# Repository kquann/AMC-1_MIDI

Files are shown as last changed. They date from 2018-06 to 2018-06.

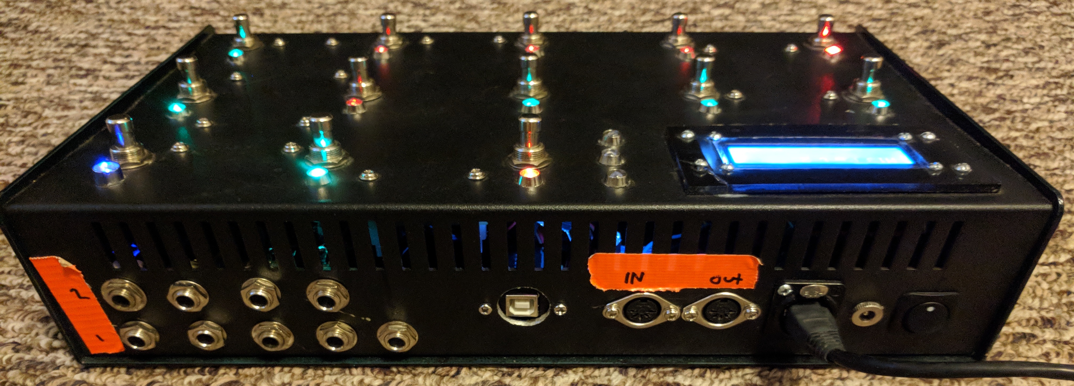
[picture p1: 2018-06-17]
resources/Photos/Back.jpg

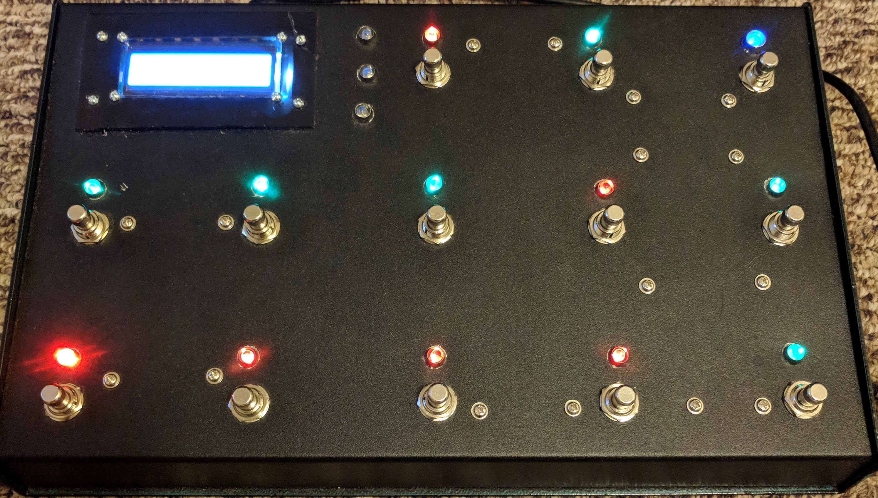
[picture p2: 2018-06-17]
resources/Photos/Front.jpg

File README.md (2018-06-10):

# AMC-1
Arduino-based MIDI foot controller

General:  
-This is a general purpose MIDI foot controller based around an Arduino Uno microcontroller.  
-Please see associated parts list and schematic for details.  
-Makes use of ShiftPWM (from elcojacobs), MIDI (from Forty Seven Effects) and LiquidCrystal595 (from tehniq3) libraries. Make sure these are placed appropriately in your Ardunio IDE library directory.  
-The controller itself has 13 switches (10 multi-use, 1 page up, 1 page down and 1 tap-tempo).  
-Support for 3 additional external switches also supported.  
-Each of 13-switches + Ext switching jacks has a multi-colored RGB LED.  
-Supports 6 expression pedals (TRS-style).  
-Interface is set up in "Pages", whereby you can scroll through different pages of presets/IAs, etc.
Each page consists of 10 different buttons, scrolling the page number increments/decrements through pages.
For instance page 1 = effects 1-10, page 2 = 11-20, etc. Note indexing starts at 0.  
-Current set-up is here as an example, change as you see fit!  

Issues:  
-Controller settings currently only changeable by modifying this code and re-flashing.  
-Make sure to disconnect MIDI out from any devices while flashing over USB!  
-MIDI over USB not tested.  
-Currently no expression calibration function.  
-MIDI in not extensively tested.  
-External switches not implemented in code.  
-While unit can support up to 6 expression pedals, code is currently set up for 1.  
-Code can be optimized (it's old), particularly with presets, but it gets the job done.

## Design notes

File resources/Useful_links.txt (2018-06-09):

Useful links:
http://www.instructables.com/id/Hookup-a-16-pin-HD44780-LCD-to-an-Arduino-in-6-sec/?ALLSTEPS
http://playground.arduino.cc/Code/ShiftRegSN74HC165N
http://www.instructables.com/id/MIDI-TO-ARDUINO/?ALLSTEPS 
https://github.com/FortySevenEffects/arduino_midi_library/
http://www.notesandvolts.com/2012/01/fun-with-arduino-midi-input-basics.html
http://www.indiana.edu/~emusic/etext/MIDI/chapter3_MIDI4.shtml
http://playground.arduino.cc/Main/MIDILibraryReference 
http://www.elcojacobs.com/using-shiftpwm-to-control-rgb-leds-with-arduino/
http://forum.arduino.cc/index.php?topic=122378.0
http://www.instructables.com/id/Home-Made-Bezel-Window-for-LCD-LED-Displays/?ALLSTEPS

Similar projects:
http://dikant.de/2015/01/18/diy-midi-footswitch-controller/
http://www.codeproject.com/Articles/38203/Arduino-Based-MIDI-Expression-Pedal
http://www.midikits.net/foot_pedal_USB_assem/foot_switch_pedal_USB_assem.htm
http://www.maxgreco.com/fun/microfoot/

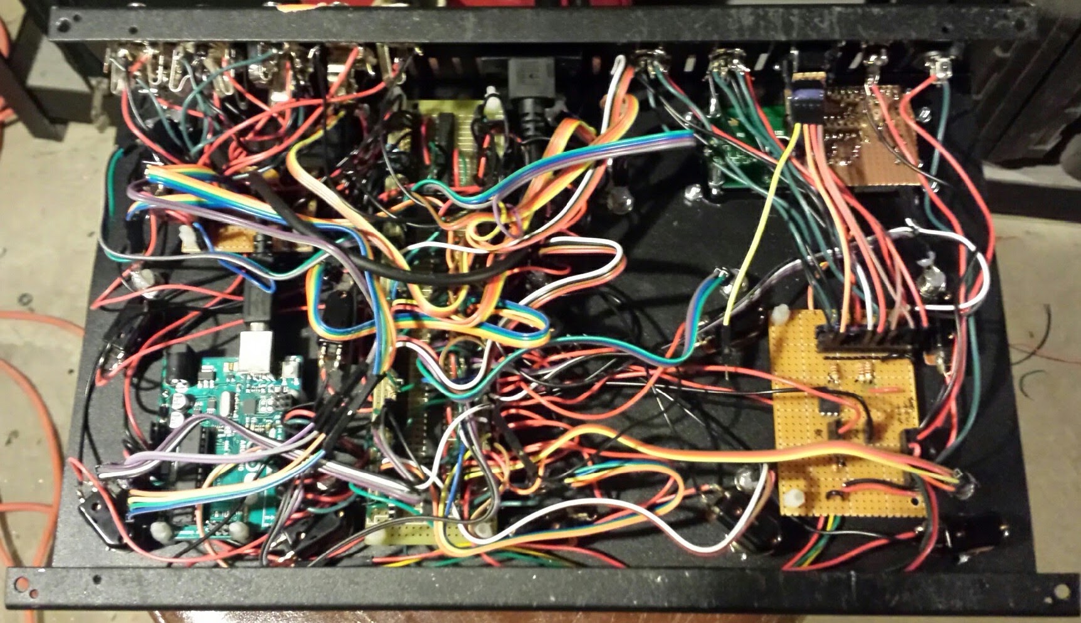
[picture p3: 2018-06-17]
resources/Photos/Inside.jpg

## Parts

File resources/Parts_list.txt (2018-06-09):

Part Name	Vendor	Cat #	Quantity	Unit Cost	Ext Cost	Link	Notes
Common Anode RGB LED (5mm)	Tayda	N/A	16	0.27	4.32	http://www.taydaelectronics.com/rgb-led-5mm.html	
Soft-touch SPST Switch	Tayda	N/A	13	1.99	25.87	http://www.taydaelectronics.com/spst-momentary-soft-touch-push-button-stomp-foots-pedal-switch.html	
"6.35MM 1/4"" STEREO CHASSIS SOCKET / JACK 3 TERMINALS"	Tayda	N/A	6	1.16	6.96	http://www.taydaelectronics.com/hardware/6-35mm-1-4-plugs-jacks/6-35mm-1-4-stereo-chassis-socket-jack-3-terminals.html	
74HC595 8 BIT SHIFT REGISTER IC	Tayda	N/A	1	0.29	0.29	http://www.taydaelectronics.com/74hc595-8-bit-shift-register-ic.html	
74HC165 74165 IC 8 BIT SHIFT REGISTER (PISO for output)	Tayda	N/A	2	0.34	0.68	http://www.taydaelectronics.com/74hc165-74165-ic-8-bit-shift-register.html	
LCD DISPLAY 16 X 2 BLUE CHARACTER WITH BACKLIGHT	Tayda	N/A	1	5.9	5.9	http://www.taydaelectronics.com/lcd-displays/lcd-display-16-x-2-blue-character-with-backlight.html	
5MM BEZEL LED HOLDER CHROME METAL	Tayda	N/A	16	0.17	2.72	http://www.taydaelectronics.com/leds/led-holders-bezels/5mm-bezel-led-holder-chrome-metal.html	
Hammond 1456PH1BKBU Enclosure	Mouser	546-1456PH1BKBU	1	34.09	34.09	http://www.mouser.com/ProductDetail/Hammond-Manufacturing/1456PH1BKBU/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	
BC550 NPN BJT	Mouser	821-BC550C-A1	1	0.13	0.13	http://www.mouser.com/Search/ProductDetail.aspx?R=BC550C_A1virtualkey53310000virtualkey821-BC550C-A1	
1K Resistor	Mouser	291-1K-RC	6	0.1	0.6	http://www.mouser.com/Search/ProductDetail.aspx?R=291-1K-RCvirtualkey21980000virtualkey291-1K-RC	
TLC5916 Shift Register	Mouser	595-TLC5916IN	6	1.54	9.24	http://www.mouser.com/Search/ProductDetail.aspx?R=TLC5916INvirtualkey59500000virtualkey595-TLC5916IN	
4N25 Optocoupler	Mouser	859-4N25	1	0.42	0.42	http://www.mouser.com/Search/ProductDetail.aspx?R=4N25virtualkey57820000virtualkey859-4N25	
3.3K resistor	Mouser	291-3.3K-RC	1	0.1	0.1	http://www.mouser.com/Search/ProductDetail.aspx?R=291-3.3K-RCvirtualkey21980000virtualkey291-3.3K-RC	
1M resistor	Mouser	291-1M-RC	1	0.1	0.1	http://www.mouser.com/ProductDetail/Xicon/291-1M-RC/?qs=sGAEpiMZZMu61qfTUdNhGzJEQZpR5iQqSPJoNLxrDWs%3d	
220 ohm resistor	Mouser	291-220-RC	3	0.1	0.3	http://www.mouser.com/Search/ProductDetail.aspx?R=291-220-RCvirtualkey21980000virtualkey291-220-RC	
Ethernet Jack	Mouser	568-NE8FDV-B	2	5.57	11.14	http://www.mouser.com/ProductDetail/Neutrik/NE8FDV-B/?qs=sGAEpiMZZMvQhAhQbXdbBoTnhlbmMnSOvi9DNYxmFOM%3d	
MIDI Port	Mouser	502-57GB5FX	4	3.12	12.48	http://www.mouser.com/ProductDetail/Switchcraft/57GB5FX/?qs=sGAEpiMZZMtAYTMy7wxAr6Injyb9yGN8XUTfjy%2fVzM4%3d	
1N4001 Diode	Mouser	512-1N4001	1	0.16	0.16	http://www.mouser.com/ProductDetail/Fairchild-Semiconductor/1N4001/?qs=sGAEpiMZZMuQUXCJI7Y4livqf9H1GTKY	
100uF capacitor	Tayda	N/A	1	0.02	0.02	http://www.taydaelectronics.com/capacitors/electrolytic-capacitors/100uf-6-3v-105c-radial-electrolytic-capacitor-6x6mm.html	
Arduino Uno	Sparkfun	11021	1	24.95	24.95	https://www.sparkfun.com/products/11021	
10K ohm Square Trimpot Variable Resistors	Amazon (Uxcell)	3362P-1-103 	1	3.88	3.88	http://www.uxcell.com/pcs-3362p1103-single-turn-trimer-pot-potentiometer-10k-ohm-p-865926.html	
2.1mmx5.5mm DC Power Jack Socket Threaded Female Connector	Amazon (Uxcell)	N/A	2	6.99	13.98	http://www.uxcell.com/21mmx55mm-power-jack-socket-threaded-female-connector-pcs-p-515271.html	
StarTech PC Mounting Computer Screws M3 x 1/4-Inches Long Standoff - 50 Pack SCREWM3	Amazon	B00032Q1J4	1	5.3	5.3	http://www.amazon.com/StarTech-Mounting-Computer-4-Inches-Standoff/dp/B00032Q1J4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	
StarTech 1-Feet Panel Mount USB Cable B to B - F/M (USBPNLBFBM1)	Amazon	USBPNLBFBM1	1	7.99	7.99	http://www.amazon.com/dp/B002M8VBIS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	
"Switchcraft 11 Mono Female 1/4-Inch Jack with Nut and Washer, Nickel Finish"	Amazon	B00C5B20QE	3	2.77	8.31	http://www.amazon.com/Switchcraft-11-Guitar-Input-Phone/dp/B00721BB44/ref=dp_ob_title_ce	
30pcs Single Row 40 Pin 2.54mm Pitch Female PCB Header Connector	Amazon	B00R1LE04I	1	$10.60	$10.60	http://www.amazon.com/Single-2-54mm-Female-Header-Connector/dp/B00R1LE04I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	
"Source One LLC 1/8 th Inch Thick 12 x 12 Inches Acrylic Plexiglass Sheet, Clear"	Amazon	B004DYW31I	1	$9.99	$9.99	http://www.amazon.com/Source-Thick-Inches-Acrylic-Plexiglass/dp/B004DYW31I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	
"Pack of 5 Prototype Universal Stripboard 2""x5"" (50ÌÑ127mm) 1000hole Phenolic Pitch 0.1"""	Amazon	B00D29X6JS	1	$6.75	$6.75	http://www.amazon.com/Prototype-Universal-Stripboard-50%C3%97127mm-1000hole/dp/B00D23G21S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	
100 Pcs Hex Threaded Spacer Offwhite Plastic PC Board Standoff	Amazon	B0087Y9FTS	1	$5.90	$5.90	http://www.amazon.com/Threaded-Spacer-Offwhite-Plastic-Standoff/dp/B0087Y9FTS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	
"BR1 Solderable PC BreadBoard, 1 Sided PCB, matches 830 tie-point breadboard with Power Rails, 1.85 x 7.05 in (47.0 x 179.1 mm)"	Amazon	B003WLJZMI	1	6.5	6.5	http://www.amazon.com/BR1-Solderable-BreadBoard-tie-point-breadboard/dp/B003WLJZMI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	
Phantom YoYo 40P Dupont Cable 10cm Male to Male 1P to 1P	Amazon	B00KOL8O6C	2	$4.99	$9.98	http://www.amazon.com/Phantom-YoYo-Dupont-Cable-10cm/dp/B00KOL8O6C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	
Sunkee 10PCS 40Pin 2.54mm Single Row Straight Female Pin Header Strip PBC Ardunio	Amazon	B00CFENE02	1	$7.98	$7.98	http://www.amazon.com/Sunkee-2-54mm-Single-Straight-Ardunio/dp/B00CFENE02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	
Phantom YoYo 40P dupont cable 200mm male to female	Amazon	B00A6SOGC4	2	$3.89	$7.78	http://www.amazon.com/dp/B00A6SOGC4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	
15Pcs 40 Pin 2.54 mm Single Row (L 11MM) Male Header for Arduino Prototype Shield DIY	Amazon	B00FR19WQA	1	$4.80	$4.80	http://www.amazon.com/Single-Header-Arduino-Prototype-Shield/dp/B00FR19WQA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	
sunkee 100pcs 1p to 1p female to female jumper wire Dupont cable for Arduino 20cm	Amazon	B00AYCON8Y	1	$6.20	$6.20	http://www.amazon.com/sunkee-100pcs-female-Dupont-Arduino/dp/B00AYCON8Y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	
Power Switch (SPST)	Amazon	B0057M4J4E	1	2.14	2.14	http://www.amazon.com/Terminal-Black-Round-Rocker-Switch/dp/B0057M4J4E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	
Misc 4-40 machine screws to mount LCD display (1 inch as narrow as possible)	Lowes / Amazon		1	2	2		
							
Total Cost					260.55		

Consumables:							
Solder							
Hookup wire							
Hot glue (for LEDS)

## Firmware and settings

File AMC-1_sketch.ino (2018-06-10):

/************************************************************************************************************************************
6/8/18
AMC-1 MIDI CONTROLLER v1.0.0
Kevin Quann
kevin.quann@gmail.com

General:
-This is a general purpose MIDI foot controller based around an Arduino Uno microcontroller.
-Please see associated parts list and schematic for details.
-Makes use of ShiftPWM, MIDI and LiquidCrystal595 libraries.
-Controller itself has 13 switches (10 multi-use, 1 page up, 1 page down and 1 tap-tempo).
-Support for 3 additional external switches also supported
-Each of 13-switches + Ext switching jacks has a  multi-colored RGB LED.
-Supports 6 expression pedals (TRS-style)
-Interface is set up in "Pages", whereby you can scroll through different pages of presets/IAs, etc.
Each page consists of 10 different buttons, scrolling the page number increments/decrements through pages.
For instance page 1 = effects 1-10, page 2 = 11-20, etc. Note indexing starts at 0.
-Current set-up is here for example, change as you see fit!

Issues:
-Controller settings currently only changeable by modifying this code and re-flashing.
-Make sure to disconnect MIDI out from any devices while flashing over USB!
-MIDI over USB not tested.
-Currently no expression calibration function.
-MIDI in not extensively tested.
-External switches not implemented in code
-While unit can support up to 6 expression pedals, code is currently set up for 1.
-Code can be optimized (it's old), particularly with presets, but it gets the job done.

Changes:
-Posted to GitHub

 ************************************************************************************************************************************/

//Set up for PISO shift-in:
//How many 74HC165N shift register chips are daisy-chained:
#define NUMBER_OF_SHIFT_CHIPS   2

//Width of data (how many ext lines).
#define DATA_WIDTH   NUMBER_OF_SHIFT_CHIPS * 8

//Width of pulse to trigger the shift register to read and latch.
#define PULSE_WIDTH_USEC   5

//Optional delay between shift register reads.
#define POLL_DELAY_MSEC   1

//Since only 2 chips are used, we may use int, >2 requires long
#define BYTES_VAL_T unsigned int

//Setting up ShiftPWM for LEDs:
#define SHIFTPWM_USE_TIMER2  // for Arduino Uno and earlier (Atmega328)

// Clock and data pins are pins from the hardware SPI, you cannot choose them yourself if you use the hardware SPI.
// Data pin is MOSI (Uno and earlier: 11)
// Clock pin is SCK (Uno and earlier: 13)
// You can choose the latch pin yourself.
const int ShiftPWM_latchPin=10;

// If your LED's turn on if the pin is low, set this to true, otherwise set it to false.
const bool ShiftPWM_invertOutputs = false; 

const bool ShiftPWM_balanceLoad = false;

const int MIDIOutPin = 1; //MIDI Out pin (UART Tx)

//Including all libraries:
#include <ShiftPWM.h>   // include ShiftPWM.h after setting the pins
#include <LiquidCrystal595.h> //included for LCD display
#include <MIDI.h> //midi library
#include <avr/pgmspace.h> //PROGMEM to store stuff in flash memory

unsigned char maxBrightness = 255;
unsigned char pwmFrequency = 75;
int numRegisters = 6; //Number of 595 shift registers used
int numRGBleds = 16;

// Defining pins for ShiftLCD
LiquidCrystal595 lcd(7,8,9);     // datapin, latchpin, clockpin

MIDI_CREATE_DEFAULT_INSTANCE(); //needed for midi library

int ploadPin        = 3;  // Connects to Parallel load pin the 165
int clockEnablePin  = 4;  // Connects to Clock Enable pin the 165
int dataPin         = 5; // Connects to the Q7 pin the 165
int clockPin        = 6; // Connects to the Clock pin the 165

boolean ExpState = 0; //Are any expression pedals in use? 0=no, 1=yes
int RawExpVals[6] = {0, 0, 0, 0, 0, 0}; //vector to store raw expression pedal values

unsigned long time; //Needed for tap tempo and blinking LEDs
unsigned long timer = 0; //used in conjunction with time
unsigned long tap_interval = 300; //defaults to 300ms
unsigned long tap_time; //Used when tap tempo is pushed 

char inChan, inDB1, inDB2; //These are variables to store incoming CC message channel, Data Byte 1 and Data Byte 2

int CurrentPage = 0;

//Define page names in flash. 8 pages is arbitrary, may be expanded or shortened.
//Names may not exceed 16 characters owing to 16x2 LCD
const PROGMEM char PageName_1[] = "Presets";
const PROGMEM char PageName_2[] = "POD HD";
const PROGMEM char PageName_3[] = "M13 Part 1";
const PROGMEM char PageName_4[] = "M13 Part 2";
const PROGMEM char PageName_5[] = "Hex 1"; 
const PROGMEM char PageName_6[] = "Hex 2";
const PROGMEM char PageName_7[] = "Unused";
const PROGMEM char PageName_8[] = "Looper";

//PageName Lookup table
const char* const PageNameTable[] PROGMEM = {PageName_1, PageName_2, PageName_3, PageName_4, PageName_5, PageName_6, PageName_7, PageName_8};

//Store effect names in Flash, number of names must be # of pages * 10 = 80 in this case.
//Names should not exceed 16 characters
const PROGMEM char EffectName_1[] = "Clean";
const PROGMEM char EffectName_2[] = "Drive";
const PROGMEM char EffectName_3[] = "Guyatone";
const PROGMEM char EffectName_4[] = "Muff";
const PROGMEM char EffectName_5[] = "Pickle";
const PROGMEM char EffectName_6[] = "Fuzz";
const PROGMEM char EffectName_7[] = "Geiger";
const PROGMEM char EffectName_8[] = "Empty";
const PROGMEM char EffectName_9[] = "Empty";
const PROGMEM char EffectName_10[] = "ALL MODS OFF";
const PROGMEM char EffectName_11[] = "FS1";
const PROGMEM char EffectName_12[] = "FS2";
const PROGMEM char EffectName_13[] = "FS3";
const PROGMEM char EffectName_14[] = "FS4";
const PROGMEM char EffectName_15[] = "FS5";
const PROGMEM char EffectName_16[] = "FS6";
const PROGMEM char EffectName_17[] = "FS7";
const PROGMEM char EffectName_18[] = "FS8";
const PROGMEM char EffectName_19[] = "Exp 1";
const PROGMEM char EffectName_20[] = "Tuner";
const PROGMEM char EffectName_21[] = "M13 2A";
const PROGMEM char EffectName_22[] = "M13 2B";
const PROGMEM char EffectName_23[] = "M13 2C";
const PROGMEM char EffectName_24[] = "Empty";
const PROGMEM char EffectName_25[] = "M13 Half time";
const PROGMEM char EffectName_26[] = "M13 1A";
const PROGMEM char EffectName_27[] = "M13 1B";
const PROGMEM char EffectName_28[] = "M13 1C";
const PROGMEM char EffectName_29[] = "Empty";
const PROGMEM char EffectName_30[] = "M13 Fwd/Rev";
const PROGMEM char EffectName_31[] = "M13 4A";
const PROGMEM char EffectName_32[] = "M13 4B";
const PROGMEM char EffectName_33[] = "M13 4C";
const PROGMEM char EffectName_34[] = "Record";
const PROGMEM char EffectName_35[] = "Play";
const PROGMEM char EffectName_36[] = "M13 3A";
const PROGMEM char EffectName_37[] = "M13 3B";
const PROGMEM char EffectName_38[] = "M13 3C";
const PROGMEM char EffectName_39[] = "Overdub";
const PROGMEM char EffectName_40[] = "Play Once";
const PROGMEM char EffectName_41[] = "Hex 1-1";
const PROGMEM char EffectName_42[] = "Hex 1-2";
const PROGMEM char EffectName_43[] = "Hex 1-3";
const PROGMEM char EffectName_44[] = "Hex 1-4";
const PROGMEM char EffectName_45[] = "Hex 1-5";
const PROGMEM char EffectName_46[] = "Hex 1-6";
const PROGMEM char EffectName_47[] = "Empty";
const PROGMEM char EffectName_48[] = "Empty";
const PROGMEM char EffectName_49[] = "Empty";
const PROGMEM char EffectName_50[] = "Empty";
const PROGMEM char EffectName_51[] = "Hex 2-1";
const PROGMEM char EffectName_52[] = "Hex 2-2";
const PROGMEM char EffectName_53[] = "Hex 2-3";
const PROGMEM char EffectName_54[] = "Hex 2-4";
const PROGMEM char EffectName_55[] = "Hex 2-5";
const PROGMEM char EffectName_56[] = "Hex 2-6";
const PROGMEM char EffectName_57[] = "Empty";
const PROGMEM char EffectName_58[] = "Empty";
const PROGMEM char EffectName_59[] = "Empty";
const PROGMEM char EffectName_60[] = "Empty";
const PROGMEM char EffectName_61[] = "Effect 61";
const PROGMEM char EffectName_62[] = "Effect 62";
const PROGMEM char EffectName_63[] = "Effect 63";
const PROGMEM char EffectName_64[] = "Effect 64";
const PROGMEM char EffectName_65[] = "Effect 65";
const PROGMEM char EffectName_66[] = "Effect 66";
const PROGMEM char EffectName_67[] = "Effect 67";
const PROGMEM char EffectName_68[] = "Effect 68";
const PROGMEM char EffectName_69[] = "Effect 69";
const PROGMEM char EffectName_70[] = "Effect 70";
const PROGMEM char EffectName_71[] = "Record";
const PROGMEM char EffectName_72[] = "Overdub";
const PROGMEM char EffectName_73[] = "Play";
const PROGMEM char EffectName_74[] = "Play Once";
const PROGMEM char EffectName_75[] = "Empty";
const PROGMEM char EffectName_76[] = "Reverse";
const PROGMEM char EffectName_77[] = "Half Time";
const PROGMEM char EffectName_78[] = "Empty";
const PROGMEM char EffectName_79[] = "Empty";
const PROGMEM char EffectName_80[] = "Empty";

const char* const EffectNameTable[] PROGMEM = //Essentially a lookup table
{
  EffectName_1, EffectName_2, EffectName_3, EffectName_4, EffectName_5,
  EffectName_6, EffectName_7, EffectName_8, EffectName_9, EffectName_10,
  EffectName_11, EffectName_12, EffectName_13, EffectName_14, EffectName_15,
  EffectName_16, EffectName_17, EffectName_18, EffectName_19, EffectName_20,
  EffectName_21, EffectName_22, EffectName_23, EffectName_24, EffectName_25,
  EffectName_26, EffectName_27, EffectName_28, EffectName_29, EffectName_30,
  EffectName_31, EffectName_32, EffectName_33, EffectName_34, EffectName_35,
  EffectName_36, EffectName_37, EffectName_38, EffectName_39, EffectName_40,
  EffectName_41, EffectName_42, EffectName_43, EffectName_44, EffectName_45,
  EffectName_46, EffectName_47, EffectName_48, EffectName_49, EffectName_50,
  EffectName_51, EffectName_52, EffectName_53, EffectName_54, EffectName_55,
  EffectName_56, EffectName_57, EffectName_58, EffectName_59, EffectName_60,
  EffectName_61, EffectName_62, EffectName_63, EffectName_64, EffectName_65,
  EffectName_66, EffectName_67, EffectName_68, EffectName_69, EffectName_70,
  EffectName_71, EffectName_72, EffectName_73, EffectName_74, EffectName_75,
  EffectName_76, EffectName_77, EffectName_78, EffectName_79, EffectName_80
};
 
//LED values for each Effect/button, must match length of effects (pages * 10) = 80, as above
//Each LED has Red, Green and Blue value associated with it, may range from 0 (off) - 255 (max brightness)
//For initialization, set LEDs to dim state (color value of 2), to be amplifed later if on  
//Assigning more than one color to "2", will result in purple, yellow, white, etc.
const PROGMEM char LEDValues[80][3] = //R, G, B
{
  {0, 0, 2}, //1
  {2, 2, 0},
  {2, 0, 0},
  {2, 0, 0},
  {2, 0, 0},
  {2, 0, 0},
  {2, 0, 0},
  {0, 0, 0},
  {0, 0, 0},
  {0, 0, 2},
  {2, 0, 0}, //11
  {2, 0, 0},
  {2, 0, 0},
  {2, 0, 0},
  {2, 0, 0},
  {2, 0, 0},
  {2, 0, 0},
  {2, 0, 0},
  {0, 0, 2},
  {0, 0, 2},
  {0, 2, 0}, //21
  {0, 0, 2},
  {0, 0, 2},
  {0, 0, 0},
  {0, 0, 2},
  {2, 0, 2},
  {2, 0, 2},
  {2, 0, 2},
  {0, 0, 0},
  {0, 0, 2},
  {2, 0, 0}, //31
  {2, 0, 0},
  {2, 0, 0},
  {2, 0, 0},
  {0, 2, 0},
  {0, 2, 0},
  {0, 2, 0},
  {0, 2, 0},
  {2, 0, 0},
  {0, 2, 0},
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
};

//MIDI values (in char values, right now nothing on chan 16, so these are effectively empty)
//PLEASE SEE: http://www.indiana.edu/~emusic/etext/MIDI/chapter3_MIDI4.shtml
//Col1: Status Byte, i.e. CC on chan 16 = 10111111 = BF = 191
//Col2: Data Byte 1, i.e. CC number
//Col3: Data Byte 2, i.e. CC value (in this case CC OFF). 
//Col4: Alternate Data Byte 2, i.e. CC value ON. 
const PROGMEM char MIDIValues[80][4] =
{
  {191, 1, 0, 127}, //SLOT 1, Clean
  {191, 11, 0, 127}, //Blues driver
  {191, 12, 0, 127}, //Big muff
  {191, 51, 0, 127}, //fuzz factory
  {191, 52, 0, 127}, //pickle
  {191, 13, 0, 127}, //geiger
  {191, 7, 0, 127},
  {191, 80, 0, 127},
  {191, 81, 0, 127}, 
  {191, 80, 0, 127}, //Empty but kills all mod effects
  {176, 51, 0, 127},  //SLOT 11, POD FS1 on Chan 1
  {176, 52, 0, 127}, //FS2
  {176, 53, 0, 127}, //FS3
  {176, 54, 0, 127}, //FS4
  {176, 55, 0, 127}, //FS5
  {176, 56, 0, 127}, //FS6
  {176, 57, 0, 127}, //FS7
  {176, 58, 0, 127}, //FS8
  {191, 59, 0, 127}, //Exp 1 toggle
  {176, 69, 0, 127}, //POD Tuner
  {177, 14, 0, 127}, //21, M13 on Chan2, Effect 2A
  {177, 15, 0, 127}, //M13 2B
  {177, 16, 0, 127}, //M13 2C
  {191, 24, 0, 127}, 
  {177, 36, 0, 127}, //M13 Looper Half time
  {177, 11, 0, 127}, //M13 1A
  {177, 12, 0, 127}, //M13 1B
  {177, 13, 0, 127}, //M13 1C
  {191, 29, 0, 127},
  {177, 85, 0, 127}, //M13 Looper Forward/Rev
  {177, 20, 0, 127}, //31, M13 4A
  {177, 21, 0, 127}, //M13 4B
  {177, 22, 0, 127}, //M13 4C
  {177, 50, 64, 127}, //M13 Record
  {177, 28, 0, 127},  //M13 Play
  {177, 17, 0, 127}, //M13 3A
  {177, 18, 0, 127}, //M13 3B
  {177, 19, 0, 127}, //M13 3C
  {177, 50, 0, 63}, //M13 Overdub
  {177, 80, 0, 127}, //M13 Play once
  {178, 80, 0, 127}, //41, Hex #1-1 on Chan 3, cc80, Mooer
  {178, 81, 0, 127}, //Hex 1-2, Shaker
  {178, 82, 0, 127}, //Hex 1-3, Fuzz factory
  {178, 83, 0, 127}, //Hex 1-4, Geiger
  {178, 84, 0, 127}, //Hex 1-5, Phaser
  {178, 85, 0, 127}, //Hex 1-6, 616
  {191, 47, 0, 127},
  {191, 48, 0, 127},
  {191, 49, 0, 127},
  {191, 50, 0, 127},
  {178, 88, 0, 127}, //51 Hex #2-1 on Chan 3, cc88, Delay?
  {178, 89, 0, 127}, //Hex 2-2, pickle
  {178, 90, 0, 127}, //Hex 2-3, big muff
  {178, 91, 0, 127}, //Hex 2-4, ??
  {178, 92, 0, 127}, //Hex 2-5, ??
  {178, 93, 0, 127}, //Hex 2-6, ??
  {191, 57, 0, 127},
  {191, 58, 0, 127},
  {191, 59, 0, 127},
  {191, 60, 0, 127},
  {191, 41, 0, 127}, //61
  {191, 42, 0, 127},
  {191, 43, 0, 127},
  {191, 44, 0, 127},
  {191, 45, 0, 127},
  {191, 46, 0, 127},
  {191, 47, 0, 127},
  {191, 48, 0, 127},
  {191, 49, 0, 127},
  {191, 50, 0, 127},
  {176, 60, 64, 127}, //71, POD Looper rec
  {176, 60, 0, 63}, //overdub
  {176, 61, 0, 127}, //POD looper play
  {176, 62, 0, 127}, //POD play once
  {191, 63, 65, 127}, //empty
  {176, 65, 0, 127}, //POD forward /rev
  {176, 68, 0, 127}, //POD half /full
  {191, 58, 0, 127},
  {191, 59, 0, 127},
  {191, 60, 0, 127}
};

//Expression values (in char values)
//This should be lengthed as more effects utilize expression values
//Col1: Effect # (starting at 0)
//Col2: Exp # (starting at 0)
//Col3: Status Byte, i.e. CC on chan 16 = 10111111 = BF = 191
//Col4: Data Byte 1, i.e. CC number
//Col5: Min Value
//Col6: Max Value
const PROGMEM char ExpValues[4][6] =
{
  {25, 0, 177, 1, 0, 127}, //Test for M13 effect in effect position 26
  {26, 0, 177, 1, 0, 127},
  {27, 0, 177, 1, 0, 127}, 
  {18, 0, 176, 1, 0, 127} //Testing for POD FS1, will send exp 1 value to POD HD exp 1
};

//Linkage table for linked effects / presets
//This table should be lengthened, shortened with addition/removal of preset switches
//Col1: Driver Effect # (Starting at 0), this is the button you press to initiate the link
//Col2: Passenger Effect # (Starting at 0), this will be the recipient of the on / off function
//Col3: Toggle, this will either turn off (0) or on (1) the passenger effect
const PROGMEM char LinkTable[140][3] =
{
  {20, 21, 0}, //IE effect in pos 20 will turn off effect in pos 21 when switched on
  {20, 22, 0}, //It will also turn off effect in pos 22
  {21, 20, 0},
  {21, 22, 0},
  {22, 20, 0},
  {22, 21, 0},
  {25, 26, 0},
  {25, 27, 0},
  {26, 25, 0},
  {26, 27, 0},
  {27, 25, 0},
  {27, 26, 0},
  {30, 31, 0}, 
  {30, 32, 0},
  {31, 30, 0},
  {31, 32, 0},
  {32, 30, 0},
  {32, 31, 0},
  {35, 36, 0}, 
  {35, 37, 0},
  {36, 35, 0},
  {36, 37, 0},
  {37, 35, 0},
  {37, 36, 0},
  {0, 42, 0}, //clean button turns off all Hex Distortion pedals
  {0, 43, 0},
  {0, 50, 0},
  {0, 51, 0},
  {0, 52, 0},
  {0, 53, 0},
  {0, 1, 0}, //also turn off any other drive preset on first page
  {0, 2, 0},
  {0, 3, 0},
  {0, 4, 0},
  {0, 5, 0}, 
  {0, 6, 0},
  {1, 53, 1}, //drive button turns on blues driver but turns off everything else
  {1, 42, 0}, 
  {1, 43, 0},
  {1, 50, 0},
  {1, 51, 0},
  {1, 52, 0},
  {1, 0, 0}, //also turn off any other drive preset on first page
  {1, 2, 0},
  {1, 3, 0},
  {1, 4, 0},
  {1, 5, 0},
  {1, 6, 0}, 
  {2, 50, 1}, //guyatone button turns on guyatone but turns off everything else
  {2, 42, 0}, 
  {2, 43, 0},
  {2, 51, 0},
  {2, 52, 0},
  {2, 53, 0},
  {2, 0, 0}, //also turn off any other drive preset on first page
  {2, 1, 0},
  {2, 3, 0},
  {2, 4, 0},
  {2, 5, 0}, 
  {2, 6, 0},
  {3, 52, 1}, //Muff button turns on muff but turns off everything else
  {3, 53, 0}, 
  {3, 42, 0},
  {3, 43, 0},
  {3, 50, 0},
  {3, 51, 0},
  {3, 0, 0}, //also turn off any other drive preset on first page
  {3, 1, 0},
  {3, 2, 0},
  {3, 4, 0},
  {3, 5, 0},
  {3, 6, 0}, 
  {4, 51, 1}, //pickle button turns on pickle but turns off everything else
  {4, 52, 0}, 
  {4, 53, 0},
  {4, 42, 0},
  {4, 43, 0},
  {4, 50, 0},
  {4, 0, 0}, //also turn off any other drive preset on first page
  {4, 1, 0},
  {4, 2, 0},
  {4, 3, 0},
  {4, 5, 0}, 
  {4, 6, 0},
  {5, 42, 1}, //FF button turns on FF but turns off everything else
  {5, 43, 0}, 
  {5, 50, 0},
  {5, 51, 0},
  {5, 52, 0},
  {5, 53, 0},
  {5, 0, 0}, //also turn off any other drive preset on first page
  {5, 1, 0},
  {5, 2, 0},
  {5, 3, 0},
  {5, 4, 0}, 
  {5, 6, 0},
  {6, 43, 1}, //geiger button turns on geiger but turns off everything else
  {6, 42, 0}, 
  {6, 50, 0},
  {6, 51, 0},
  {6, 52, 0},
  {6, 53, 0},
  {6, 0, 0}, //also turn off any other drive preset on first page
  {6, 1, 0},
  {6, 2, 0},
  {6, 3, 0},
  {6, 4, 0}, 
  {6, 5, 0},
  {72, 70, 0}, //When play on POD looper is hit, stop recording
  {72, 73, 0}, //When also stop play once
  {73, 70, 0}, //likewise, when play once is hit, stop recording
  {73, 72, 0}, //and also stop normal play
  {34, 33, 0}, //When play on M13 looper is hit, stop recording
  {34, 39, 0}, //When also stop play once
  {39, 33, 0}, //likewise, when play once is hit, stop recording
  {39, 34, 0}, //and also stop normal play
  {9, 10, 0}, //Master kill FS1-8
  {9, 11, 0},
  {9, 12, 0},
  {9, 13, 0},
  {9, 14, 0},
  {9, 15, 0},
  {9, 16, 0},
  {9, 17, 0},
  {9, 20, 0}, //Master Kill all M13 except keep FX loop on
  {9, 21, 0},
  {9, 22, 0},
  {9, 25, 0},
  {9, 26, 0},
  {9, 27, 0},
  {9, 30, 1},//Keep effects loop on
  {9, 31, 0},
  {9, 32, 0}, 
  {9, 35, 0},
  {9, 36, 0},
  {9, 37, 0}, 
  {9, 40, 0}, //Kill Hex mods / delays (all mods)
  {9, 41, 0},
  {9, 44, 0},
  {9, 45, 0}
};
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
void loop()
{    
  time = millis(); //gets current time
  
//Read the state of all buttons:
    pinValues = read_shift_regs();

//Only do stuff if a button was pushed:
//Should probably put most code in here
    if(pinValues != oldPinValues) // Note there is not currently any reassigning of oldPinValues, so only reacting to any button presses
    {
      for (int x = 0; x < 10; x++) //Check each button 1-10 for a change and toggle its effect state
      {
        if((pinValues >> x) & 1) 
        {
          EffectState[x + CurrentPage * 10] = !EffectState[x + CurrentPage * 10]; //Toggle effect state
          LinkToggle(x + CurrentPage * 10); //Ensures linked effects are handled
          SendMIDI(x + CurrentPage * 10); // Sends the appropriate MIDI message
          ChangeLEDs();
          DisplayEffectName(x + CurrentPage * 10); //This is slow and thus after LED update
          delay(250); //Crude debouncing 250ms
        }
      }
      
      if((pinValues >> 10) & 1) //Page Down
      {
        if(CurrentPage == 0)
        {
          CurrentPage = 7; //Goes to page 6 if down is pressed from page 0
        }
        else
        {
          CurrentPage = CurrentPage - 1; //Otherwise just decrement
        }
        DisplayPageName();
        ChangeLEDs();
        delay(250); //Crude debouncing 250ms
      }
      
      if((pinValues >> 11) & 1) //Page Up
      {
        if(CurrentPage == 7)
        {
          CurrentPage = 0; //Goes to page 0 if up is pressed from page 6
        }
        else
        {
          CurrentPage = CurrentPage + 1; //Otherwise just increment
        }
        DisplayPageName();
        ChangeLEDs();
        delay(250); //Crude debouncing 250ms
      }

      if((pinValues >> 12) & 1) //Tap Tempo
      {
        if((time - tap_time > 100) && (time - tap_time < 2000)) // must be between 100ms and 2s
        {
          tap_interval = time - tap_time; //reassign interval
        }
        TapTempo(); //send MIDI and get new tap_time
        delay(200); //Crude debouncing 200ms, little more conservative since it's tap tempo
      }
      
      //Evaluate if any of the Expression effects are now on:
      GetExpStatus();
      
    }

   //if any expression pedals are in use, execute the exp function 
   if (ExpState == 1)
  {
    GetExpStatus();
    delay(5); //Expression works better with a slight delay to prevent excessive sampling and serial port slowdown
  }

  //Testing Blinking LEDs:
  if (time - timer > tap_interval)
  {
    ShiftPWM.SetRGB(12, 0, 0, 5); //Tap tempo LED on (blue)
    timer = time; //reset timer
  }
  if (time - timer > 50) //wait 50ms
  {
    ShiftPWM.SetRGB(12, 0, 0, 2); //Tap tempo LED off (blue)
  }
   
//READ MIDI IN
if (MIDI.read())                // Is there a MIDI message incoming ?
    {
        switch(MIDI.getType())      // Get the type of the message we caught
        {
            case midi::ControlChange:       // If it is a Control Change,
                inChan = MIDI.getChannel(); //assign channel
                inChan = inChan + 175; //add this to get the total byte value
                inDB1 = MIDI.getData1(); //assign databyte 1
                inDB2 = MIDI.getData2(); //assign databyte 2
                CheckMIDIIn(); //Check if this applies to any effect state
                break;
            // See the online reference for other message types
            default:
                break;
        }
    }

    delay(POLL_DELAY_MSEC);
}
